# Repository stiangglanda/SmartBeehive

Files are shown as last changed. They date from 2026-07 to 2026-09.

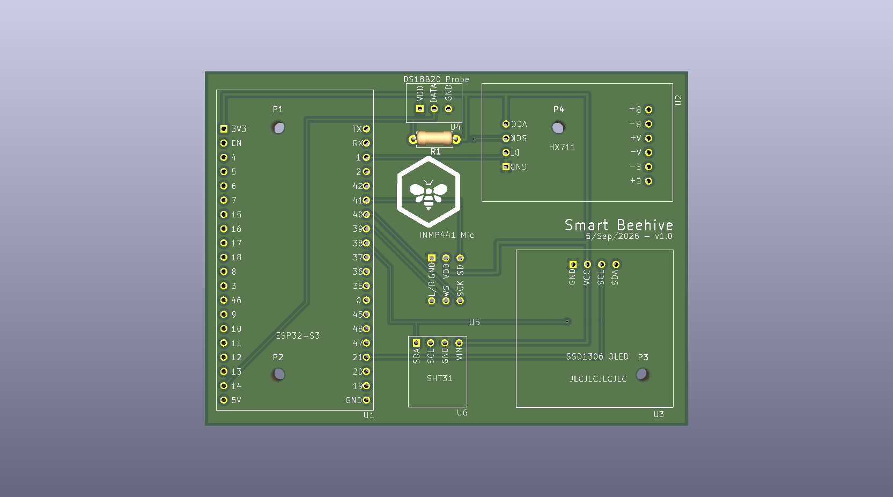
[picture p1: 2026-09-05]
hardware/SmartBeehive3DRender.png

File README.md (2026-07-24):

<p align="center">
  favicon  
</p>

<h1 align="center">SmartBeehive Monitoring System</h1>

This project is an IoT-based beehive monitoring system. An ESP32-S3 collects real-time beehive data (weight, temperature, audio, and images) and sends it over Wi-Fi to a central STM32MP215F-DK Linux server running Docker.

<p align="center">
  <a href="https://www.youtube.com/watch?v=g_EhRMFEKto">
    
    <br>
    ▶ Watch Video
  </a>
</p>



## Project Structure

This project is divided into two main components:
* **firmware(this Repo)**: The ESP-IDF C source code for the ESP32-S3 edge node.
* **[Web Dashboard](https://github.com/stiangglanda/smart-beehive-dashboard)**: The static Next.js frontend application used to visualize the collected hive metrics and media.

## System Architecture

```mermaid
graph TD
    subgraph ESP32-S3 [ESP32-S3 Beehive Node]
        S_Scale[HX711 Load Cell] --> ESP[ESP32-S3]
        S_Temp[SHT31 Sensor] --> ESP
        S_Probe[DS18B20 Probe] --> ESP
        S_Mic[INMP441 Mic] --> ESP
        S_Cam[OV2640 Cam] --> ESP
        ESP --> Disp[SSD1306 OLED]
    end

    subgraph Server [Any Linux Server - Docker]
        Broker[Mosquitto MQTT]
        NodeRED[Node-RED]
        Influx[InfluxDB v2]
        Nginx[Nginx Web Server]
        Storage[(Shared File Storage)]
    end

    ESP -->|1. MQTT Telemetry| Broker
    Broker -->|2. Forward Data| NodeRED
    NodeRED -->|3. Write Metrics| Influx
    
    ESP -->|4. HTTP POST Images/Audio| NodeRED
    NodeRED -->|5. Save Files| Storage
    Nginx -->|6. Serve Files| Storage
    
    NodeRED -->|7. MQTT Commands| Broker
    Broker -->|8. Forward Commands| ESP

    subgraph Clients [Dashboard Clients]
        UI[Web Dashboard] -->|Fetch /data.json & /history.json| Nginx
        UI -->|Fetch /images & /audio| Nginx
    end
```

## Hardware Components

### Edge Node
* ESP32-S3 development board
* OV2640 Camera
* INMP441 I2S Microphone
* HX711 ADC & Load Cell
* SHT31-D Temp & Humidity Sensor
* DS18B20 Temp Probe
* SSD1306 OLED Display

### Server Host
* **STM32MP215F-DK** (or any device running Linux like Raspberry Pi, PC, or VPS)

## Pinout Mapping (ESP32-S3)

| Component / Signal | ESP32-S3 Pin |
| :--- | :--- |
| **HX711 DOUT** | GPIO 1 |
| **HX711 SCK** | GPIO 2 |
| **I2C SDA** (SHT31 & OLED) | GPIO 21 |
| **I2C SCL** (SHT31 & OLED) | GPIO 38 |
| **DS18B20 Data** | GPIO 14 |
| **INMP441 I2S WS** | GPIO 39 |
| **INMP441 I2S SCK** | GPIO 40 |
| **INMP441 I2S SD** | GPIO 41 |
| **OV2640 Camera** | Standard DVP pinout |

## Server Deployment

To deploy the entire server stack (Mosquitto, Node-RED, InfluxDB, Nginx) on your Linux host using the provided `server/docker-compose.yml`:

```bash
# Start the stack in background (detached mode)
docker-compose up -d

# Verify that all 4 containers are successfully running
docker ps
```

## Edge Node Build Guide

### Configure Credentials
Update the configuration section at the top of the main source file:

```c
#define WIFI_SSID           "Your_SSID"
#define WIFI_PASS           "Your_Password"
#define SERVER_IP           "Your_Server_IP"
```

### Compile and Flash
Execute the following commands in your ESP-IDF terminal environment:

```bash
idf.py set-target esp32s3

idf.py build

idf.py flash
```

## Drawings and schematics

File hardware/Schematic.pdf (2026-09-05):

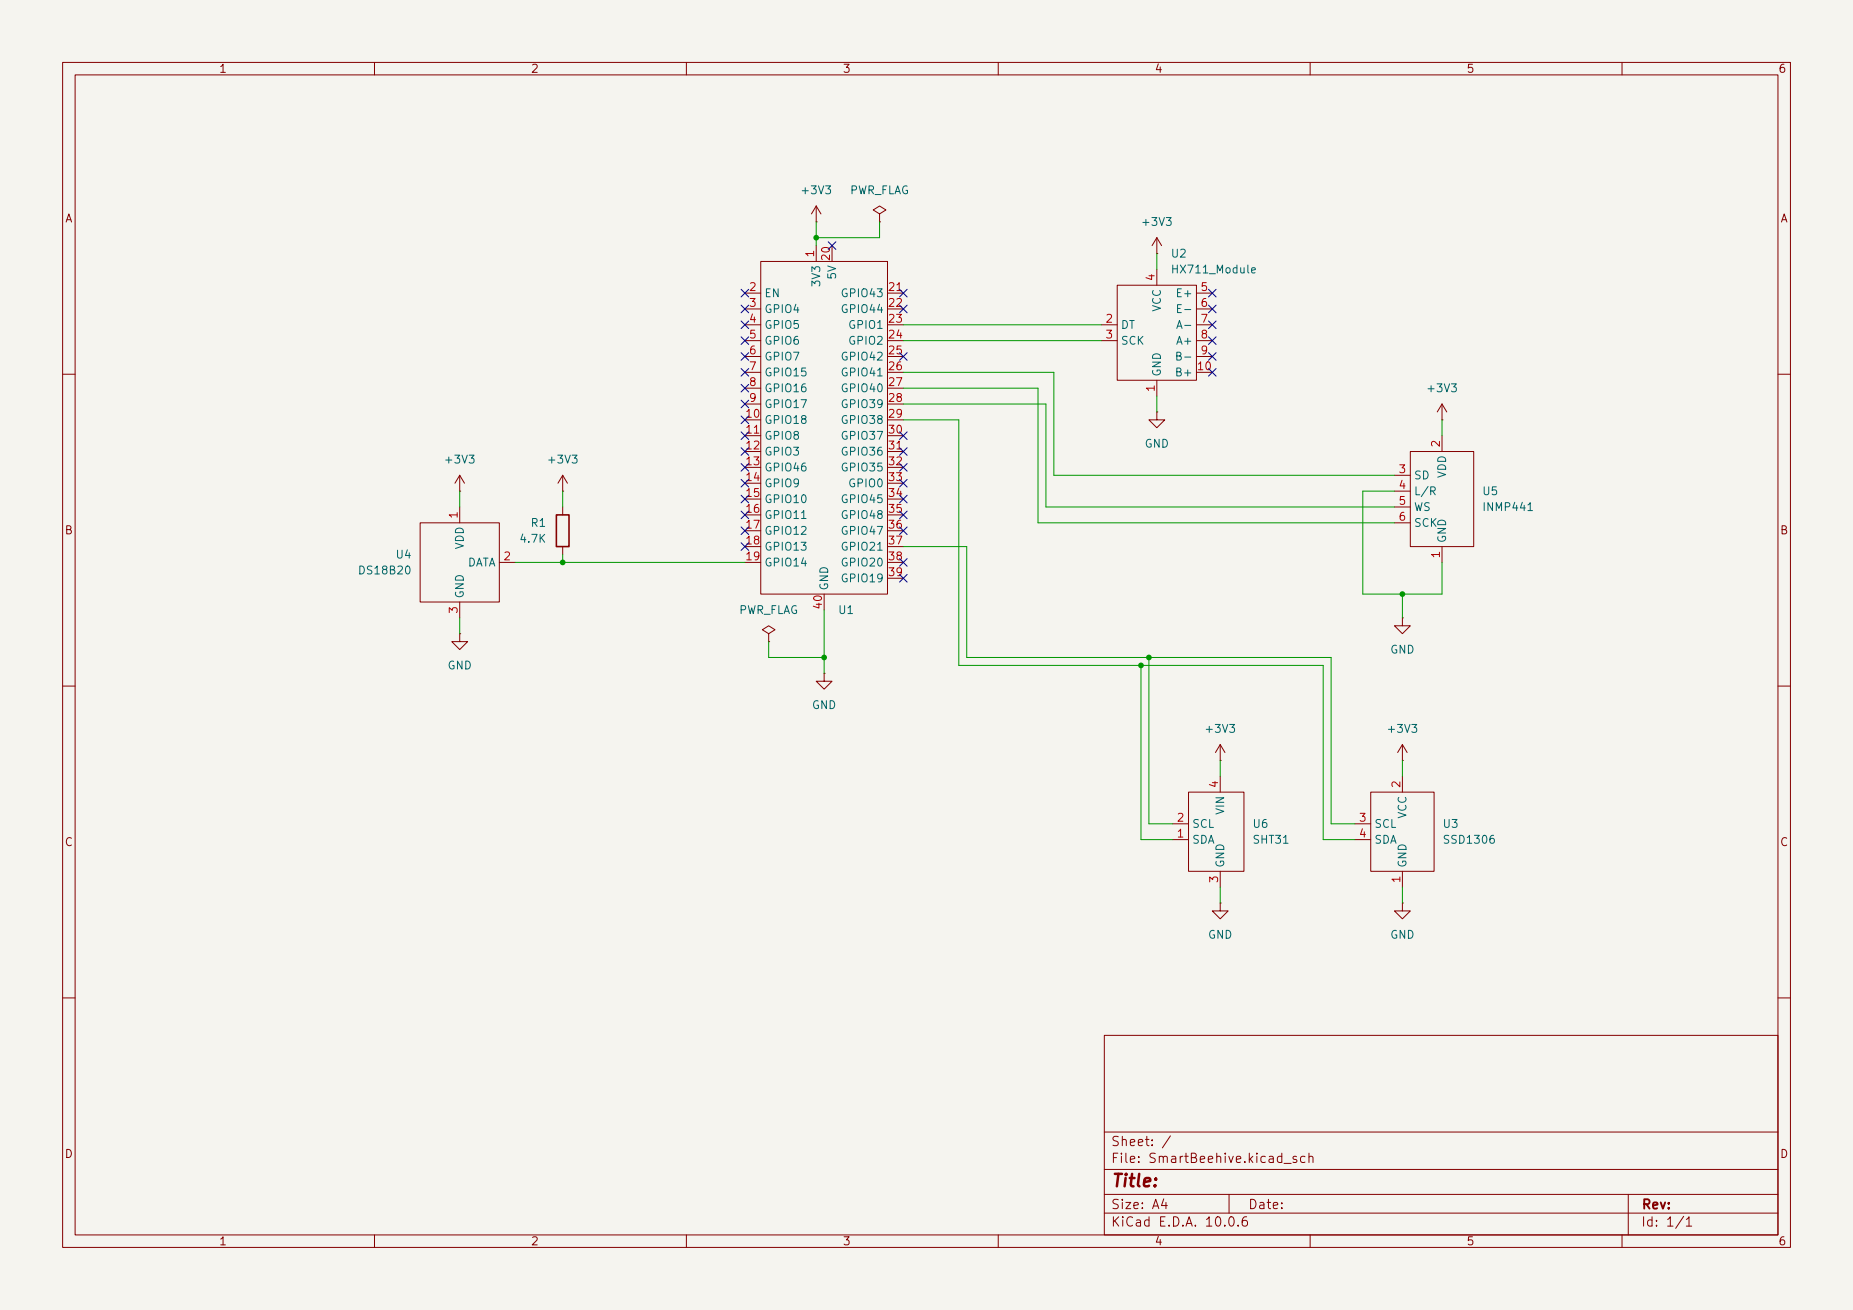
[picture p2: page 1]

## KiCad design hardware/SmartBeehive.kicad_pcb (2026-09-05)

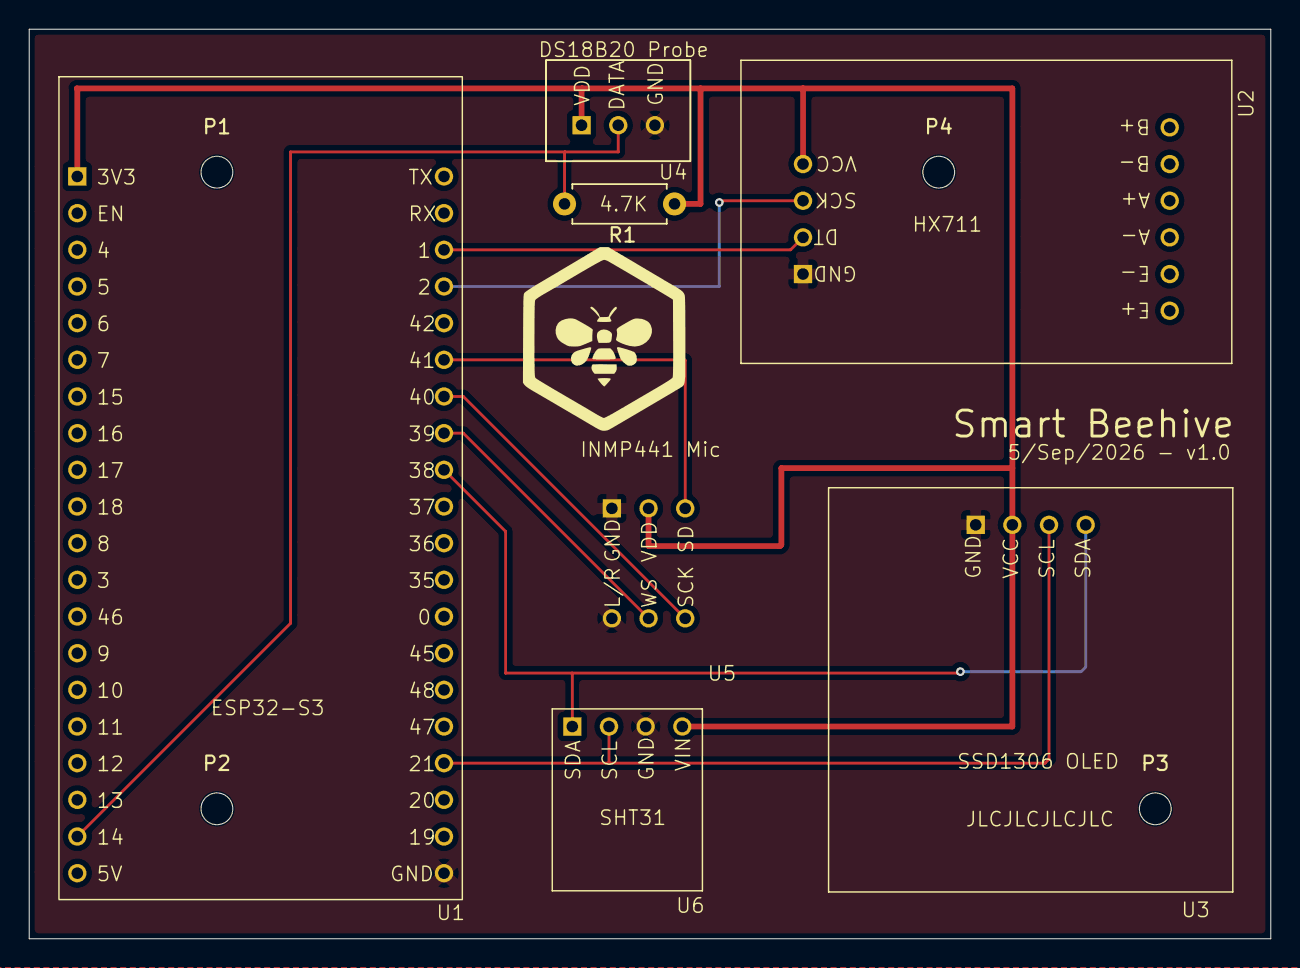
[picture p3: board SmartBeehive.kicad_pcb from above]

Board: 4 copper layers, 86.0 x 63.0 mm, 11 parts (0 on the bottom side), 10 nets.

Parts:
P1, P2, P3, P4: MountingHole_2.2mm_M2
R1: 4.7K; R_Axial_DIN0207_L6.3mm_D2.5mm_P7.62mm_Horizontal
U1: Freenove_ESP32_S3
U2: HX711_Module; HX711_V2
U3: SSD1306
U4: DS18B20
U5: INMP441
U6: SHT31

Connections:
+3V3: R1.1, U1.1 (3V3), U2.4 (VCC), U3.2 (VCC), U4.1 (VDD), U5.2 (VDD), U6.4 (VIN)
GND: U1.40 (GND), U2.1 (GND), U3.1 (GND), U4.3 (GND), U5.1 (GND), U5.4 (L/R), U6.3 (GND)
unnamed: U1.23 (GPIO1), U2.2 (DT)
unnamed: U1.24 (GPIO2), U2.3 (SCK)
unnamed: R1.2, U1.19 (GPIO14), U4.2 (DATA)
unnamed: U1.37 (GPIO21), U3.3 (SCL), U6.2 (SCL)
unnamed: U1.29 (GPIO38), U3.4 (SDA), U6.1 (SDA)
unnamed: U1.28 (GPIO39), U5.5 (WS)
unnamed: U1.27 (GPIO40), U5.6 (SCK)
unnamed: U1.26 (GPIO41), U5.3 (SD)

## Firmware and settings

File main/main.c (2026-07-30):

#include <stdio.h>
#include <string.h>
#include <inttypes.h>
#include "sdkconfig.h"
#include "freertos/FreeRTOS.h"
#include "freertos/task.h"
#include "driver/gpio.h"
#include "esp_rom_sys.h"
#include "driver/i2s_std.h"
#include "driver/i2c_master.h"  
#include "esp_err.h"
#include "esp_camera.h"
#include "esp_wifi.h"
#include "esp_event.h"
#include "nvs_flash.h"
#include "esp_netif.h"
#include "esp_http_client.h"
#include "mqtt_client.h"

#define WIFI_SSID      "Your_SSID"
#define WIFI_PASS      "Your_Password"
#define SERVER_IP      "Your_Server_IP"

#define HX711_DOUT_PIN      GPIO_NUM_1
#define HX711_SCK_PIN       GPIO_NUM_2
#define I2S_WS_PIN          GPIO_NUM_39
#define I2S_SCK_PIN         GPIO_NUM_40
#define I2S_SD_PIN          GPIO_NUM_41
#define I2C_MASTER_SDA_IO   GPIO_NUM_21
#define I2C_MASTER_SCL_IO   GPIO_NUM_38
#define DS18B20_PIN         GPIO_NUM_14

#define I2C_MASTER_NUM      I2C_NUM_0
#define I2C_MASTER_FREQ_HZ  100000
#define SHT31_ADDR          0x44
#define OLED_ADDR           0x3C

struct wav_header {
    char riff[4];
    uint32_t size;
    char wave[4];
    char fmt[4];
    uint32_t fmt_len;
    uint16_t format;
    uint16_t channels;
    uint32_t samplerate;
    uint32_t byterate;
    uint16_t align;
    uint16_t bps;
    char data_id[4];
    uint32_t data_len;
} __attribute__((packed));

static camera_config_t camera_config = {
    .pin_pwdn = -1,
    .pin_reset = -1,
    .pin_xclk = 15,
    .pin_sccb_sda = 4,
    .pin_sccb_scl = 5,
    .pin_d7 = 16,
    .pin_d6 = 17,
    .pin_d5 = 18,
    .pin_d4 = 12,
    .pin_d3 = 10,
    .pin_d2 = 8,
    .pin_d1 = 9,
    .pin_d0 = 11,
    .pin_vsync = 6,
    .pin_href = 7,
    .pin_pclk = 13,
    .xclk_freq_hz = 20000000,
    .ledc_timer = LEDC_TIMER_0,
    .ledc_channel = LEDC_CHANNEL_0,
    .pixel_format = PIXFORMAT_JPEG,
    .frame_size = FRAMESIZE_VGA,
    .jpeg_quality = 12,
    .fb_count = 1,
    .fb_location = CAMERA_FB_IN_DRAM
};

float scale_factor = 27102.500f;
int32_t offset = 524532;
i2s_chan_handle_t rx_chan;
esp_mqtt_client_handle_t mqtt_client = NULL;

volatile float current_weight = 0.0f;
volatile float current_temp = 0.0f;       
volatile float current_hum = 0.0f;        
volatile float current_probe_temp = 0.0f; 
volatile uint32_t current_activity = 0;
volatile bool wifi_connected = false;
volatile bool mqtt_connected = false;

portMUX_TYPE ds_mux = portMUX_INITIALIZER_UNLOCKED;
i2c_master_bus_handle_t i2c_bus_handle;
i2c_master_dev_handle_t oled_dev_handle;
i2c_master_dev_handle_t sht31_dev_handle;

// I2C Bus Mutex
SemaphoreHandle_t i2c_mutex = NULL;

int32_t hx711_read_average(int times);
int32_t hx711_read_raw(void);
void upload_photo(void);
void upload_audio(void);
void mqtt_app_start(void);

void upload_file_to_server(const char *path, const uint8_t *buffer, size_t len, const char *content_type) {
    char url[128];
    snprintf(url, sizeof(url), "http://%s:1880%s", SERVER_IP, path);

    esp_http_client_config_t config = {
        .url = url,
        .method = HTTP_METHOD_POST,
    };
    esp_http_client_handle_t client = esp_http_client_init(&config);
    esp_http_client_set_header(client, "Content-Type", content_type);
    esp_http_client_set_post_field(client, (const char *)buffer, len);

    esp_err_t err = esp_http_client_perform(client);
    if (err == ESP_OK) {
        printf("Upload successfully completed: %s (%zu bytes)\n", path, len);
    } else {
        printf("Upload failed for %s: %s\n", path, esp_err_to_name(err));
    }
    esp_http_client_cleanup(client);
}

void i2c_init(void) {
    i2c_master_bus_config_t bus_config = {
        .clk_source = I2C_CLK_SRC_DEFAULT,
        .i2c_port = I2C_MASTER_NUM,
        .scl_io_num = I2C_MASTER_SCL_IO,
        .sda_io_num = I2C_MASTER_SDA_IO,
        .glitch_ignore_cnt = 7,
        .flags.enable_internal_pullup = true,
    };
    ESP_ERROR_CHECK(i2c_new_master_bus(&bus_config, &i2c_bus_handle));

    i2c_device_config_t oled_dev_config = {
        .dev_addr_length = I2C_ADDR_BIT_LEN_7,
        .device_address = OLED_ADDR,
        .scl_speed_hz = I2C_MASTER_FREQ_HZ
    };
    ESP_ERROR_CHECK(i2c_master_bus_add_device(i2c_bus_handle, &oled_dev_config, &oled_dev_handle));

    i2c_device_config_t sht31_dev_config = {
        .dev_addr_length = I2C_ADDR_BIT_LEN_7,
        .device_address = SHT31_ADDR,
        .scl_speed_hz = I2C_MASTER_FREQ_HZ
    };
    ESP_ERROR_CHECK(i2c_master_bus_add_device(i2c_bus_handle, &sht31_dev_config, &sht31_dev_handle));
}

const uint8_t min_font[][5] = {
    {0x3e, 0x51, 0x49, 0x45, 0x3e}, // 0
    {0x00, 0x42, 0x7f, 0x40, 0x00}, // 1
    {0x42, 0x61, 0x51, 0x49, 0x46}, // 2
    {0x21, 0x41, 0x45, 0x4b, 0x31}, // 3
    {0x18, 0x14, 0x12, 0x7f, 0x10}, // 4
    {0x27, 0x45, 0x45, 0x45, 0x39}, // 5
    {0x3c, 0x4a, 0x49, 0x49, 0x30}, // 6
    {0x01, 0x71, 0x09, 0x05, 0x03}, // 7
    {0x36, 0x49, 0x49, 0x49, 0x36}, // 8
    {0x06, 0x49, 0x49, 0x29, 0x1e}, // 9
    {0x00, 0x00, 0x00, 0x00, 0x00}, // 10: Space
    {0x00, 0x60, 0x60, 0x00, 0x00}, // 11: .
    {0x08, 0x08, 0x08, 0x08, 0x08}, // 12: -
    {0x3e, 0x41, 0x41, 0x41, 0x22}, // 13: C
    {0x23, 0x13, 0x08, 0x64, 0x62}, // 14: %
    {0x7f, 0x08, 0x14, 0x22, 0x41}, // 15: k
    {0x30, 0x4a, 0x4a, 0x4a, 0x7c}, // 16: g
    {0x01, 0x01, 0x7f, 0x01, 0x01}, // 17: T
    {0x7f, 0x20, 0x18, 0x20, 0x7f}, // 18: W
    {0x7f, 0x08, 0x08, 0x08, 0x7f}, // 19: H
    {0x06, 0x09, 0x09, 0x06, 0x00}, // 20: o (Degree symbol)
    {0x7e, 0x11, 0x11, 0x11, 0x7e}, // 21: A
    {0x3e, 0x41, 0x41, 0x41, 0x3e}, // 22: O
    {0x7f, 0x08, 0x14, 0x22, 0x41}, // 23: K
    {0x7f, 0x02, 0x0c, 0x02, 0x7f}, // 24: M
    {0x3e, 0x41, 0x51, 0x21, 0x5e}, // 25: Q
    {0x7f, 0x09, 0x09, 0x09, 0x01}, // 26: F
    {0x00, 0x44, 0x7d, 0x40, 0x00}  // 27: i
};

int get_font_idx(char c) {
    if (c >= '0' && c <= '9') {
        return c - '0';
    }
    switch (c) {
        case ' ':  return 10;
        case '.':  return 11;
        case '-':  return 12;
        case 'C':  return 13;
        case '%':  return 14;
        case 'k':  return 15;
        case 'g':  return 16;
        case 'T':  return 17;
        case 'W':  return 18;
        case 'H':  return 19;
        case 'o':  return 20; 
        case 'A':  return 21;
        case 'O':  return 22;
        case 'K':  return 23;
        case 'M':  return 24;
        case 'Q':  return 25;
        case 'F':  return 26;
        case 'i':  return 27;
        default:   return 10;
    }
}

void oled_cmd(uint8_t c) {
    uint8_t d[2] = {0x00, c};
    i2c_master_transmit(oled_dev_handle, d, 2, 100);
}

void oled_init(void) {
    uint8_t cmds[] = {
        0xAE, 0x20, 0x02, 0x21, 0, 127, 0x22, 0, 7, 
        0xC8, 0x40, 0x81, 0xCF, 0xA1, 0xA6, 0xA8, 0x3F, 
        0xDA, 0x12, 0xD3, 0x00, 0xD5, 0x80, 0xD9, 0xF1, 
        0xDB, 0x40, 0x8D, 0x14, 0xAF
    };
    for (size_t i = 0; i < sizeof(cmds); i++) {
        oled_cmd(cmds[i]);
    }
}

void oled_clear(void) {
    for (int page = 0; page < 8; page++) {
        oled_cmd(0xB0 + page);
        oled_cmd(0x00);
        oled_cmd(0x10);
        for (int col = 0; col < 128; col++) {
            uint8_t d[2] = {0x40, 0x00};
            i2c_master_transmit(oled_dev_handle, d, 2, 100);
        }
    }
}

void oled_print(uint8_t page, uint8_t col, const char* str) {
    oled_cmd(0xB0 + page);
    oled_cmd(0x00 + (col & 0x0F));
    oled_cmd(0x10 + ((col >> 4) & 0x0F));
    
    int current_col = col;
    
    while (*str) {
        if (current_col >= 128 - 6) { 
            break; 
        }
        
        int idx = get_font_idx(*str++);
        
        for (int i = 0; i < 5; i++) {
            uint8_t d[2] = {0x40, min_font[idx][i]};
            i2c_master_transmit(oled_dev_handle, d, 2, 100);
        }
        uint8_t space[2] = {0x40, 0x00};
        i2c_master_transmit(oled_dev_handle, space, 2, 100);
        
        current_col += 6;
    }
    
    while (current_col < 128) {
        uint8_t blank[2] = {0x40, 0x00};
        i2c_master_transmit(oled_dev_handle, blank, 2, 100);
        current_col++;
    }
}

void ds18b20_init(void) {
    gpio_set_direction(DS18B20_PIN, GPIO_MODE_INPUT_OUTPUT_OD);
    gpio_set_pull_mode(DS18B20_PIN, GPIO_PULLUP_ONLY);
    gpio_set_level(DS18B20_PIN, 1);
}

bool ds18b20_reset(void) {
    gpio_set_level(DS18B20_PIN, 0);
    esp_rom_delay_us(500);
    
    portENTER_CRITICAL(&ds_mux);
    gpio_set_level(DS18B20_PIN, 1);
    esp_rom_delay_us(55);
    bool present = !gpio_get_level(DS18B20_PIN);
    portEXIT_CRITICAL(&ds_mux);
    
    esp_rom_delay_us(400);
    return present;
}

void ds18b20_write_bit(uint8_t bit) {
    portENTER_CRITICAL(&ds_mux);
    gpio_set_level(DS18B20_PIN, 0);
    esp_rom_delay_us(2);
    if (bit) {
        gpio_set_level(DS18B20_PIN, 1);
    }
    esp_rom_delay_us(60);
    gpio_set_level(DS18B20_PIN, 1);
    esp_rom_delay_us(2);
    portEXIT_CRITICAL(&ds_mux);
}

uint8_t ds18b20_read_bit(void) {
    uint8_t bit = 0;
    portENTER_CRITICAL(&ds_mux);
    gpio_set_level(DS18B20_PIN, 0);
    esp_rom_delay_us(2);
    gpio_set_level(DS18B20_PIN, 1);
    esp_rom_delay_us(10);
    bit = gpio_get_level(DS18B20_PIN);
    esp_rom_delay_us(50);
    portEXIT_CRITICAL(&ds_mux);
    return bit;
}

void ds18b20_write_byte(uint8_t data) {
    for (int i = 0; i < 8; i++) {
        ds18b20_write_bit(data & 0x01);
        data >>= 1;
    }
}

uint8_t ds18b20_read_byte(void) {
    uint8_t data = 0;
    for (int i = 0; i < 8; i++) {
        if (ds18b20_read_bit()) {
            data |= (1 << i);
        }
    }
    return data;
}

void hx711_init(void) {
    gpio_reset_pin(HX711_DOUT_PIN);
    gpio_set_direction(HX711_DOUT_PIN, GPIO_MODE_INPUT);
    gpio_reset_pin(HX711_SCK_PIN);
    gpio_set_direction(HX711_SCK_PIN, GPIO_MODE_OUTPUT);
    gpio_set_level(HX711_SCK_PIN, 0);
}

int32_t hx711_read_raw(void) {
    int wait_counter = 0;
    while (gpio_get_level(HX711_DOUT_PIN) == 1) {
        vTaskDelay(pdMS_TO_TICKS(10));
        wait_counter++;
        if (wait_counter > 100) {
            return 0;
        }
    }
    
    int32_t count = 0;
    portMUX_TYPE mux = portMUX_INITIALIZER_UNLOCKED;
    portENTER_CRITICAL(&mux);
    
    for (int i = 0; i < 24; i++) {
        gpio_set_level(HX711_SCK_PIN, 1);
        esp_rom_delay_us(1);
        count = count << 1;
        gpio_set_level(HX711_SCK_PIN, 0);
        esp_rom_delay_us(1);
        if (gpio_get_level(HX711_DOUT_PIN)) {
            count++;
        }
    }
    
    gpio_set_level(HX711_SCK_PIN, 1);
    esp_rom_delay_us(1);
    gpio_set_level(HX711_SCK_PIN, 0);
    esp_rom_delay_us(1);
    portEXIT_CRITICAL(&mux);
    
    if (count & 0x800000) {
        count |= 0xFF000000;
    }
    return count;
}

int32_t hx711_read_average(int times) {
    int64_t sum = 0;
    for (int i = 0; i < times; i++) {
        sum += hx711_read_raw();
    }
    return (int32_t)(sum / times);
}

void hx711_tare(void) {
    printf("Scale: Taring...\n");
    offset = hx711_read_average(50);
    printf("Scale: Done.\n");
}

void init_microphone(void) {
    // Uses I2S_NUM_1 to prevent resources conflicts with the camera module
    i2s_chan_config_t chan_cfg = I2S_CHANNEL_DEFAULT_CONFIG(I2S_NUM_1, I2S_ROLE_MASTER);
    ESP_ERROR_CHECK(i2s_new_channel(&chan_cfg, NULL, &rx_chan));
    
    i2s_std_config_t std_cfg = {
        .clk_cfg  = I2S_STD_CLK_DEFAULT_CONFIG(16000), 
        .slot_cfg = I2S_STD_PHILIPS_SLOT_DEFAULT_CONFIG(I2S_DATA_BIT_WIDTH_32BIT, I2S_SLOT_MODE_STEREO), 
        .gpio_cfg = {
            .mclk = I2S_GPIO_UNUSED,
            .bclk = I2S_SCK_PIN,
            .ws = I2S_WS_PIN,
            .dout = I2S_GPIO_UNUSED,
            .din = I2S_SD_PIN,
            .invert_flags = {0}
        },
    };
    ESP_ERROR_CHECK(i2s_channel_init_std_mode(rx_chan, &std_cfg));
    ESP_ERROR_CHECK(i2s_channel_enable(rx_chan));
}

static void wifi_event_handler(void* arg, esp_event_base_t event_base, int32_t event_id, void* event_data) {
    if (event_base == WIFI_EVENT && event_id == WIFI_EVENT_STA_START) {
        esp_wifi_connect();
    } else if (event_base == WIFI_EVENT && event_id == WIFI_EVENT_STA_DISCONNECTED) {
        wifi_connected = false;
        mqtt_connected = false;
        esp_wifi_connect();
        printf("WiFi: Connection lost. Reconnecting...\n");
    } else if (event_base == IP_EVENT && event_id == IP_EVENT_STA_GOT_IP) {
        ip_event_got_ip_t* event = (ip_event_got_ip_t*) event_data;
        printf("WiFi: Connected. IP: " IPSTR "\n", IP2STR(&event->ip_info.ip));
        wifi_connected = true;
        mqtt_app_start();
    }
}

void wifi_init_sta(void) {
    ESP_ERROR_CHECK(esp_netif_init());
    ESP_ERROR_CHECK(esp_event_loop_create_default());
    esp_netif_create_default_wifi_sta();
    
    wifi_init_config_t cfg = WIFI_INIT_CONFIG_DEFAULT();
    ESP_ERROR_CHECK(esp_wifi_init(&cfg));
    ESP_ERROR_CHECK(esp_event_handler_instance_register(WIFI_EVENT, ESP_EVENT_ANY_ID, &wifi_event_handler, NULL, NULL));
    ESP_ERROR_CHECK(esp_event_handler_instance_register(IP_EVENT, IP_EVENT_STA_GOT_IP, &wifi_event_handler, NULL, NULL));

    wifi_config_t wifi_config = {
        .sta = {
            .ssid = WIFI_SSID,
            .password = WIFI_PASS
        }
    };
    ESP_ERROR_CHECK(esp_wifi_set_mode(WIFI_MODE_STA));
    ESP_ERROR_CHECK(esp_wifi_set_config(WIFI_IF_STA, &wifi_config));
    ESP_ERROR_CHECK(esp_wifi_start());
}

static void mqtt_event_handler(void *handler_args, esp_event_base_t base, int32_t event_id, void *event_data) {
    esp_mqtt_event_handle_t event = event_data;
    switch ((esp_mqtt_event_id_t)event_id) {
        case MQTT_EVENT_CONNECTED:
            printf("MQTT: Connected.\n");
            mqtt_connected = true;
            esp_mqtt_client_subscribe(mqtt_client, "bienen/befehl", 0);
            break;
        case MQTT_EVENT_DISCONNECTED:
            printf("MQTT: Connection lost.\n");
            mqtt_connected = false;
            break;
        case MQTT_EVENT_DATA:
            printf("MQTT: Command received: %.*s\n", event->data_len, event->data);
            if (strncmp(event->data, "take_photo", event->data_len) == 0) {
                upload_photo();
            } else if (strncmp(event->data, "record_audio", event->data_len) == 0) {
                upload_audio();
            }
            break;
        default:
            break;
    }
}

void mqtt_app_start(void) {
    char url[64];
    snprintf(url, sizeof(url), "mqtt://%s", SERVER_IP);
    
    esp_mqtt_client_config_t mqtt_cfg = {
        .broker.address.uri = url
    };
    mqtt_client = esp_mqtt_client_init(&mqtt_cfg);
    esp_mqtt_client_register_event(mqtt_client, ESP_EVENT_ANY_ID, mqtt_event_handler, NULL);
    esp_mqtt_client_start(mqtt_client);
}

void upload_photo(void) {
    printf("Camera: Capturing photo...\n");
    camera_fb_t *fb = esp_camera_fb_get();
    if (!fb) {
        printf("Camera: Capture failed!\n");
        return;
    }
    upload_file_to_server("/upload/image", fb->buf, fb->len, "image/jpeg");
    esp_camera_fb_return(fb);
}

void upload_audio(void) {
    printf("Audio: Capturing 3 seconds (DSP Noise-Filter enabled)...\n");
    
    uint32_t sample_rate = 16000;
    uint32_t duration_sec = 3;
    uint32_t num_samples = sample_rate * duration_sec;
    uint32_t data_size = num_samples * sizeof(int16_t);
    uint32_t total_size = data_size + sizeof(struct wav_header);

    uint8_t *wav_buf = malloc(total_size);
    if (!wav_buf) {
        printf("Audio: Allocation failed (insufficient RAM).\n");
        return;
    }

    struct wav_header header = {
        .riff = {'R', 'I', 'F', 'F'},
        .size = total_size - 8,
        .wave = {'W', 'A', 'V', 'E'},
        .fmt = {'f', 'm', 't', ' '},
        .fmt_len = 16,
        .format = 1,
        .channels = 1,
        .samplerate = sample_rate,
        .byterate = sample_rate * sizeof(int16_t),
        .align = sizeof(int16_t),
        .bps = 16,
        .data_id = {'d', 'a', 't', 'a'},
        .data_len = data_size
    };
    memcpy(wav_buf, &header, sizeof(struct wav_header));

    const uint32_t chunk_frames = 256;
    int32_t *raw_buf = malloc(chunk_frames * 2 * sizeof(int32_t));
    if (!raw_buf) {
        free(wav_buf);
        printf("Audio: Temp-buffer allocation failed.\n");
        return;
    }

    uint32_t samples_collected = 0;
    int16_t *pcm_ptr = (int16_t *)(wav_buf + sizeof(struct wav_header));
    
    // DSP filter parameters
    float prev_x = 0; 
    float prev_y = 0; 
    float alpha = 0.99f; // High-pass filter (DC removal)
    float lpf_y = 0; 
    float beta = 0.35f;  // Low-pass filter (noise smoothing)
    float gain = 6.5f;

    while (samples_collected < num_samples) {
        size_t bytes_read = 0;
        uint32_t chunk = (num_samples - samples_collected > chunk_frames) ? 
                          chunk_frames : (num_samples - samples_collected);
                          
        esp_err_t res = i2s_channel_read(rx_chan, raw_buf, chunk * 2 * sizeof(int32_t), &bytes_read, portMAX_DELAY);
        if (res == ESP_OK) {
            uint32_t read_samples = bytes_read / sizeof(int32_t);
            uint32_t read_frames = read_samples / 2;
            
            for (uint32_t i = 0; i < read_frames; i++) {
                int32_t raw_sample = raw_buf[i * 2] >> 14;
                
                // DC offset removal (High-pass)
                float x = (float)raw_sample;
                float y = x - prev_x + alpha * prev_y;
                prev_x = x; 
                prev_y = y;
                
                // High frequency filter (Low-pass)
                lpf_y = beta * y + (1.0f - beta) * lpf_y;
                
                // Apply digital gain
                int32_t corrected = (int32_t)(lpf_y * gain);
                
                // Noise gate for silent intervals
                if (corrected < 180 && corrected > -180) {
                    corrected /= 5; 
                }
                
                // Hard clipping protection
                if (corrected > 32767) {
                    corrected = 32767;
                }
                if (corrected < -32768) {
                    corrected = -32768;
                }
                
                *pcm_ptr++ = (int16_t)corrected;
            }
            samples_collected += read_frames;
        } else {
            break;
        }
    }
    free(raw_buf);

    printf("Audio: Capturing complete (%lu bytes). Uploading...\n", total_size);
    upload_file_to_server("/upload/audio", wav_buf, total_size, "audio/wav");
    free(wav_buf);
}

void scale_task(void *pvParameters) {
    while (1) {
        int32_t current_raw = hx711_read_average(50);
        int32_t raw_without_offset = current_raw - offset;
        current_weight = (float)raw_without_offset / scale_factor;
        vTaskDelay(pdMS_TO_TICKS(1000));
    }
}

void sht31_task(void *pvParameters) {
    uint8_t reset_cmd[2]   = {0x30, 0xA2};
    uint8_t heater_on[2]   = {0x30, 0x6D};
    uint8_t heater_off[2]  = {0x30, 0x66};
    uint8_t measure_cmd[2] = {0x24, 0x00};
    
    uint8_t data[6]; 
    int wet_counter = 0;

    if (i2c_mutex != NULL) {
        xSemaphoreTake(i2c_mutex, portMAX_DELAY);
        i2c_master_transmit(sht31_dev_handle, reset_cmd, 2, 1000);
        xSemaphoreGive(i2c_mutex);
        vTaskDelay(pdMS_TO_TICKS(50)); 
    }

    while (1) {
        if (i2c_mutex != NULL) {
            xSemaphoreTake(i2c_mutex, portMAX_DELAY);
            memset(data, 0, sizeof(data));
            
            if (i2c_master_transmit(sht31_dev_handle, measure_cmd, 2, 1000) == ESP_OK) {
                vTaskDelay(pdMS_TO_TICKS(20));
                
                if (i2c_master_receive(sht31_dev_handle, data, 6, 1000) == ESP_OK) {
                    if (data[0] == 0x00 && data[1] == 0x00) {
                        wet_counter++;
                        i2c_master_transmit(sht31_dev_handle, heater_on, 2, 1000);
                    } else {
                        if (wet_counter > 0) {
                            i2c_master_transmit(sht31_dev_handle, heater_off, 2, 1000);
                            wet_counter = 0;
                        }
                        
                        uint16_t t_raw = (data[0] << 8) | data[1]; 
                        uint16_t h_raw = (data[3] << 8) | data[4];
                        current_temp = -45.0f + 175.0f * ((float)t_raw / 65535.0f);
                        current_hum = 100.0f * ((float)h_raw / 65535.0f);
                    }
                }
            }
            xSemaphoreGive(i2c_mutex); 
        }
        
        vTaskDelay(pdMS_TO_TICKS(2000));
    }
}
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
void app_main(void) {
    printf("Starting SmartBeehive System...\n");

    esp_err_t ret = nvs_flash_init();
    if (ret == ESP_ERR_NVS_NO_FREE_PAGES || ret == ESP_ERR_NVS_NEW_VERSION_FOUND) {
        ESP_ERROR_CHECK(nvs_flash_erase());
        ret = nvs_flash_init();
    }
    ESP_ERROR_CHECK(ret);

    hx711_init();
    i2c_init();
    i2c_mutex = xSemaphoreCreateMutex();
    vTaskDelay(pdMS_TO_TICKS(500));

    // Note: Initialize the camera first before starting I2S microphone tasks 
    // to avoid bus conflicts on power-on reset.
    printf("Camera: Initializing OV2640...\n");
    ESP_ERROR_CHECK(esp_camera_init(&camera_config));
    printf("Camera: Initialized successfully.\n");

    printf("Microphone: Initializing INMP441...\n");
    init_microphone();
    printf("Microphone: Initialized successfully.\n");

    wifi_init_sta();

    xTaskCreatePinnedToCore(scale_task, "Scale Task", 4096, NULL, 2, NULL, 0);
    xTaskCreatePinnedToCore(sht31_task, "SHT31 Task", 4096, NULL, 2, NULL, 0);
    xTaskCreatePinnedToCore(ds18b20_task, "DS18B20 Task", 4096, NULL, 2, NULL, 0);
    xTaskCreatePinnedToCore(display_task, "Display Task", 4096, NULL, 2, NULL, 0);
    xTaskCreatePinnedToCore(telemetry_task, "Telemetry Task", 4096, NULL, 2, NULL, 0);
}

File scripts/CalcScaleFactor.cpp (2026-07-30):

#include "HX711.h"

const int LOADCELL_DOUT_PIN = 3;
const int LOADCELL_SCK_PIN = 2;

const long OFFSET = 543820;

const float KNOWN_WEIGHT_KG = 2.0f;

#define NUM_READINGS 500

HX711 scale;

void setup()
{
    Serial.begin(57600);

    scale.begin(LOADCELL_DOUT_PIN, LOADCELL_SCK_PIN);

    Serial.println("HX711 Scale Factor Calibration");
    Serial.println();

    Serial.println("Place the known weight on the scale.");
    Serial.println("Waiting 10 seconds...");
    
    delay(10000);

    Serial.println("Starting measurements...");

    long long sum = 0;

    for (int i = 0; i < NUM_READINGS; i++)
    {
        while (!scale.is_ready())
        {
            delay(10);
        }

        long reading = scale.read();
        sum += reading;

        if (i % 50 == 0)
        {
            Serial.print("Measurement ");
            Serial.print(i);
            Serial.print("/");
            Serial.println(NUM_READINGS);
        }

        delay(50);
    }

    long raw_average = sum / NUM_READINGS;

    long difference = raw_average - OFFSET;

    float scale_factor = difference / KNOWN_WEIGHT_KG;

    Serial.println();
    Serial.println("===============================");
    Serial.print("Raw average: ");
    Serial.println(raw_average);

    Serial.print("Difference: ");
    Serial.println(difference);

    Serial.print("Scale factor: ");
    Serial.println(scale_factor, 3);

    Serial.println("===============================");
}

void loop()
{
}

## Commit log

2026-07-23 added node red flows and updated readme
2026-07-30 fixed i2c bus conflicts with a the i2c_mutex and fixed oled print fragments
    [main.c]
2026-08-30 Add SmartBeehiveLib to fp-lib-table and create lock file for project
    [SmartBeehive.kicad_pcb, SmartBeehive.kicad_sch]
2026-08-30 Add SmartBeehiveLib footprints for HX711 and SSD1306, and update library references
    [SmartBeehive.kicad_sch]
2026-08-30 Add HX711_V2 footprint and update SSD1306 UUIDs; fix SmartBeehive schematic and lock file
    [SmartBeehive.kicad_sch]
2026-08-30 Refactor SHT31 symbol pin assignments and add footprint to SmartBeehiveLib
    [SmartBeehive.kicad_sch]
2026-08-30 Add footprints for INMP441 and DS18B20; update schematic properties
    [SmartBeehive.kicad_sch]
2026-08-30 Refactor code structure for improved readability and maintainability
    [SmartBeehive.kicad_pcb, SmartBeehive.kicad_sch]
2026-09-05 Update component footprints and UUIDs in SmartBeehiveLib
    - Modified the HX711_V2.kicad_mod file to update UUIDs and adjust text sizes for better visibility.
    - Adjusted the INMP441.kicad_mod file, including repositioning text labels and updating UUIDs.
    - Updated SHT31.kicad_mod with new UUIDs and repositioned several text labels for clarity.
    - Revised SSD1306.kicad_mod to enhance text positioning and update UUIDs.
    - Added lock files for the PCB, project, and schematic to track changes and prevent conflicts.
    [SmartBeehive.kicad_pcb]
2026-09-05 Remove lock files for KiCad PCB, Pro, and Schematic to prevent conflicts during collaborative development.
    [SmartBeehive.kicad_pcb]
2026-09-05 Add lock file for SmartBeehive project to track user session
    [SmartBeehive.kicad_pcb]
2026-09-05 Add Gerber files and drill files for Smart Beehive project
    - Created copper layer files: SmartBeehive-In1_Cu.g1 and SmartBeehive-In2_Cu.g2
    - Added non-plated through hole drill file: SmartBeehive-NPTH.drl
    - Added plated through hole drill file: SmartBeehive-PTH.drl
    - Included a zip archive of the gerber files: SmartBeehive_v1_gerbers.zip
    [SmartBeehive-B_Mask.gbs, SmartBeehive-B_Paste.gbp, SmartBeehive-B_Silkscreen.gbo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]
2026-09-05 Add schematic PDF and 3D render image; remove lock file to prevent conflicts
2026-11-06 Update README with PCB and Schematic sections
    Added schematic section and updated PCB image.
2026-11-06 Update README with new image and PCB section
    Added a new image to the README and updated PCB section.
